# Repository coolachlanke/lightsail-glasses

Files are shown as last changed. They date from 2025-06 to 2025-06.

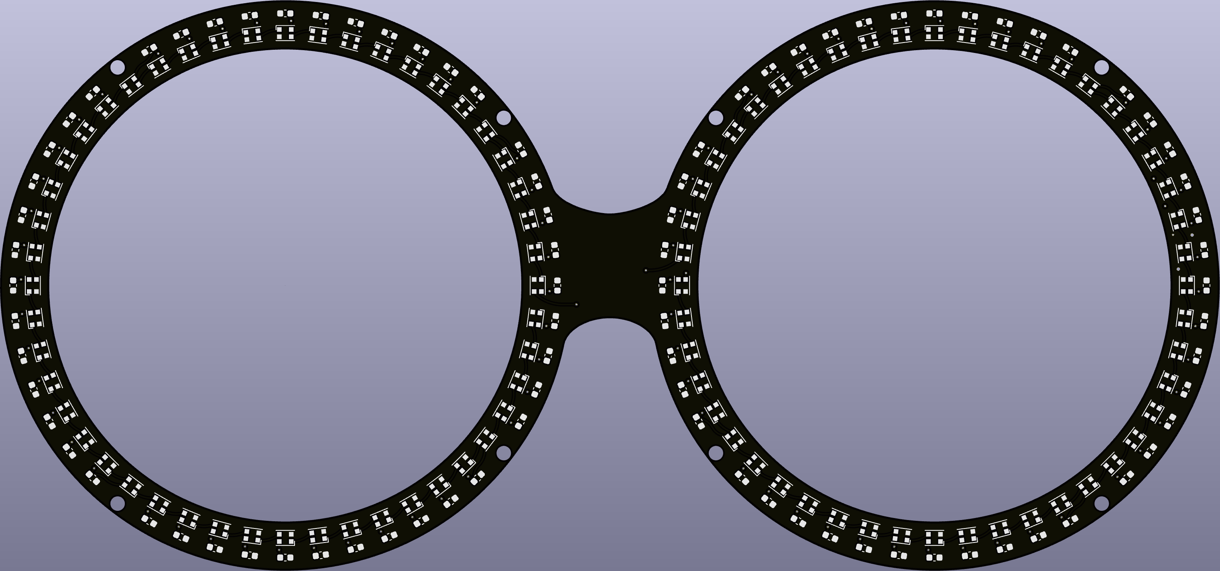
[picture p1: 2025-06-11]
Images/lsg_pcb_topsilk2.png

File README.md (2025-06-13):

# LightSail Glasses

**Colourful party glasses powered by WS2812B RGB LEDs, ESP32-C3, and WiFi.**  
Designed for festivals, raves, and fun.

---

## 🛠️ Tech Stack

- **Microcontroller:** ESP32-C3 (USB-C, WiFi)
- **PCBs:** Custom logic board and WS2812B carrier board developed with KiCAD 8
- **LEDs:** 2x WS2812B 48-pixel rings (96 total)
- **Power:** USB-C (5V) with onboard voltage regulation
- **Firmware:** Custom ESP32 firmware written in C++ in PlatformIO (Arduino framework)
- **App:** Custom ReactNative app for WiFi control
- **Animations:** Multiple visual modes, sinusoidal brightness effects, pulses, swirls, etc.

---

> Designed by Lachlan Cooke in late 2023.
> Check out [lachlancooke.com/projects](https://www.lachlancooke.com/projects) für mehr details.

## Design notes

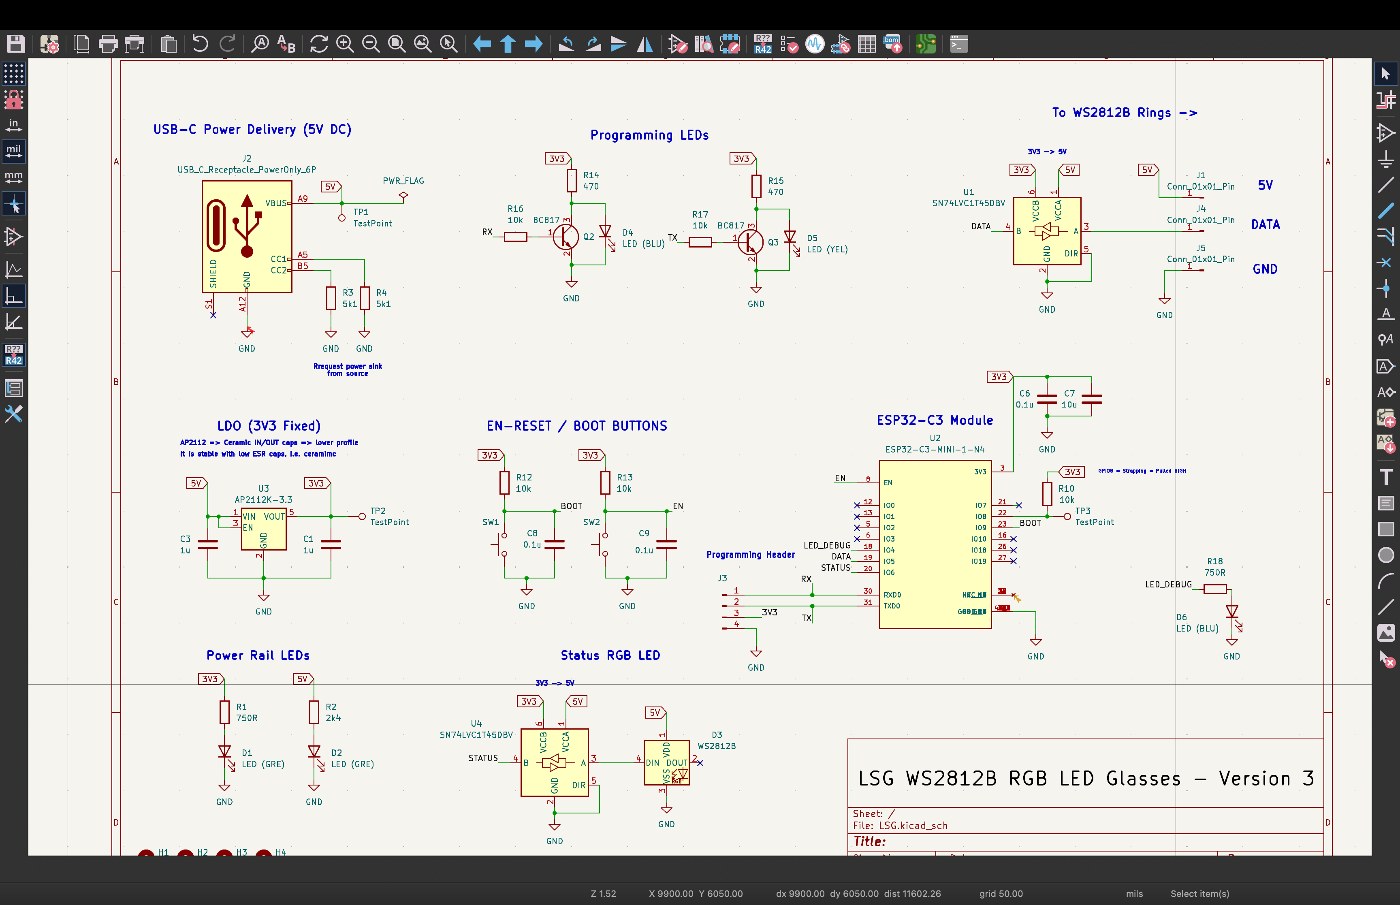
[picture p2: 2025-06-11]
Images/LSG_Logic_Schematic.png

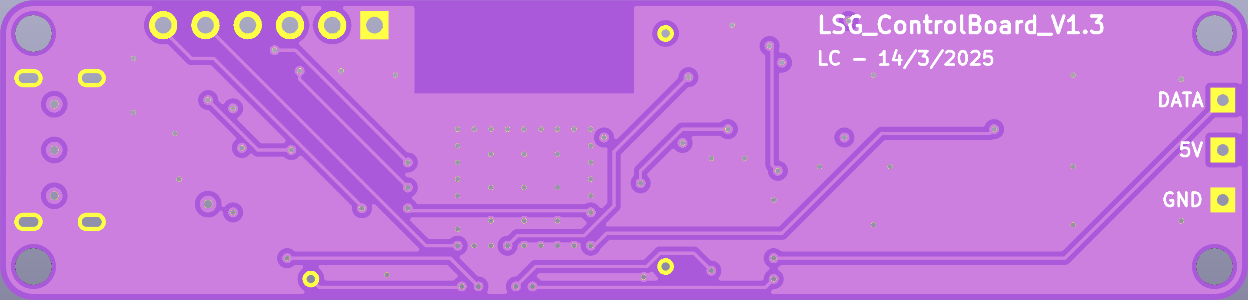
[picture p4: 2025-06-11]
Images/LSG_LogicPCB_V1.3_BottomSilk.png

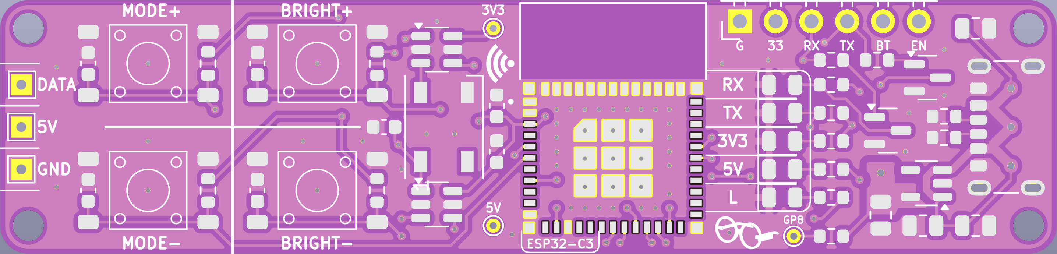
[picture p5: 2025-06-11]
Images/LSG_LogicPCB_V1.3_FrontSilk.png

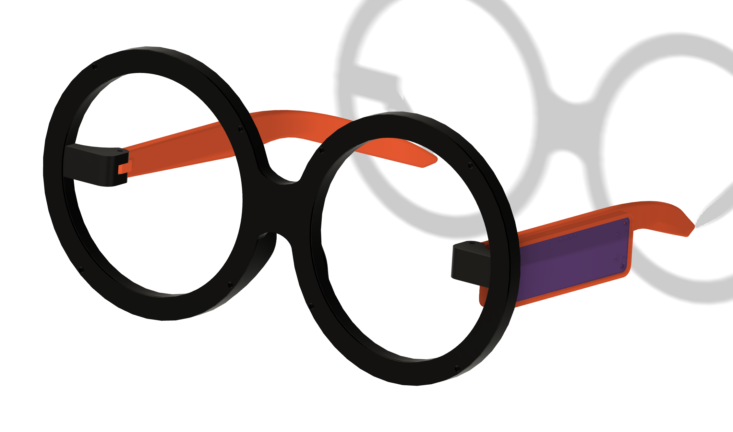
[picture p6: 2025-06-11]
Images/Glasses_Silk.png

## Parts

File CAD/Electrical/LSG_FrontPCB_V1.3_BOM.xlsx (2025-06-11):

Comment | Designator | Footprint | JLCPCB Part #
Cap 100nF 0603 | C1, C2, C3, C4, C5, C7, C8, C9, C10, C11, C12, C13, C14, C15, C16, C17, C19, C20, C21, C22, C23, C24, C25, C26, C27, C28, C29, C30, C31, C33, C34, C35, C36, C37, C38, C39, C40, C41, C42, C43, C45, C46, C47, C48, C49, C50, C51, C52, C53, C55, C56, C57, C58, C59, C60, C61, C62, C63, C64, C65, C67, C68, C69, C70, C71, C72, C73, C74, C75, C76, C77, C78, C79, C81, C82, C83, C84, C85, C86, C87, C88, C89, C90, C91, C93, C94, C95, C96 | Capacitor_SMD:C_0603_1608Metric | C1588
WS2812B 2020 | D1, D2, D3, D4, D5, D6, D7, D8, D9, D10, D11, D12, D13, D14, D15, D16, D17, D18, D19, D20, D21, D22, D23, D24, D25, D26, D27, D28, D29, D30, D31, D32, D33, D34, D35, D36, D37, D38, D39, D40, D41, D42, D43, D44, D45, D46, D47, D48, D49, D50, D51, D52, D53, D54, D55, D56, D57, D58, D59, D60, D61, D62, D63, D64, D65, D66, D67, D68, D69, D70, D71, D72, D73, D74, D75, D76, D77, D78, D79, D80, D81, D82, D83, D84, D85, D86, D87, D88, D89, D90, D91, D92, D93, D94, D95, D96 | LED_SMD:LED_WS2812B-2020_PLCC4_2.0x2.0mm | C965555

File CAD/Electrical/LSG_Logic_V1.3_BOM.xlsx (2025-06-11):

Comment | Designator | Footprint | JLCPCB Part #
1u 0805 | C1,C3 | Capacitor_SMD:C_0805_2012Metric | C28323
0.1u 0603 | C2,C4,C5,C6,C8,C10 | Capacitor_SMD:C_0603_1608Metric | C1588
10u 0603 | C7 | Capacitor_SMD:C_0603_1608Metric | C19702
10u 0805 | C11,C12 | Capacitor_SMD:C_0805_2012Metric | C15850
LED (GRE) 0805 | D1,D2 | Diode_SMD:D_0805_2012Metric | C965815
WS2812B | D3 | LED_SMD:LED_WS2812B_PLCC4_5.0x5.0mm_P3.2mm | C2843785
LED (BLU) 0805 | D4,D6 | Diode_SMD:D_0805_2012Metric | C965817
LED (YEL) 0805 | D5 | Diode_SMD:D_0805_2012Metric | C965814
USB_C_Receptacle_PowerOnly_6P | J2 | Connector_USB:USB_C_Receptacle_GCT_USB4125-xx-x-0190_6P_TopMnt_Horizontal | C456012
BC817 | Q2,Q3 | Package_TO_SOT_SMD:SOT-23 | C52801
750R 0603 | R1,R18 | Resistor_SMD:R_0603_1608Metric | C25257
2k4 0603 | R2 | Resistor_SMD:R_0603_1608Metric | C22940
5k1 0603 | R3,R4 | Resistor_SMD:R_0603_1608Metric | C105580
10k 0603 | R5,R6,R7,R8,R10,R16,R17 | Resistor_SMD:R_0603_1608Metric | C98220
470R 0603 | R14,R15 | Resistor_SMD:R_0603_1608Metric | C23179
SW_Push | SW3,SW4,SW5,SW7 | LC_CustomFootprint:SW_PUSH_6.0mm_SMT | C255812
SN74LVC1T45DBV | U1,U4 | Package_TO_SOT_SMD:SOT-23-6 | C7843
ESP32-C3-MINI-1-N4 | U2 | ESP32_C3_MINI_1_N4:XCVR_ESP32-C3-MINI-1-N4 | C2838502
AP2112K-3.3 | U3 | Package_TO_SOT_SMD:SOT-23-5 | C51118

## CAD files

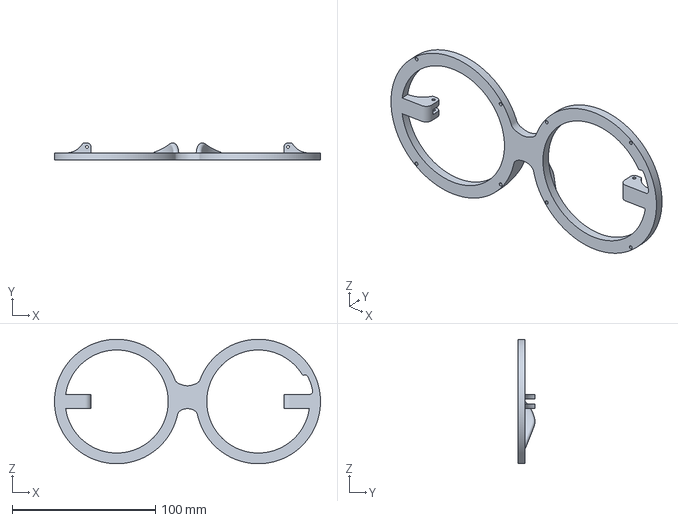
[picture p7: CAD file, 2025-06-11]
CAD/Mechanical/LSG_Mainframe_V1.3.3mf
186.0 x 12.0 x 87.0 mm

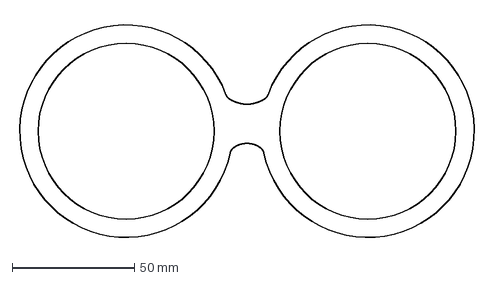
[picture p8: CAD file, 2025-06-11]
CAD/Mechanical/LSG_FrontPCB_EdgeCuts5.dxf
188.9 x 92.0 mm

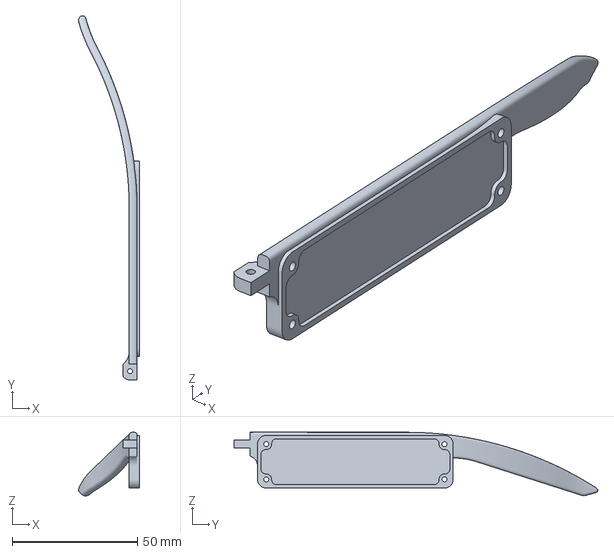
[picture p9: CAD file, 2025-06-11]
CAD/Mechanical/LSG_RightTemple_V1.3.3mf
24.4 x 145.0 x 25.3 mm

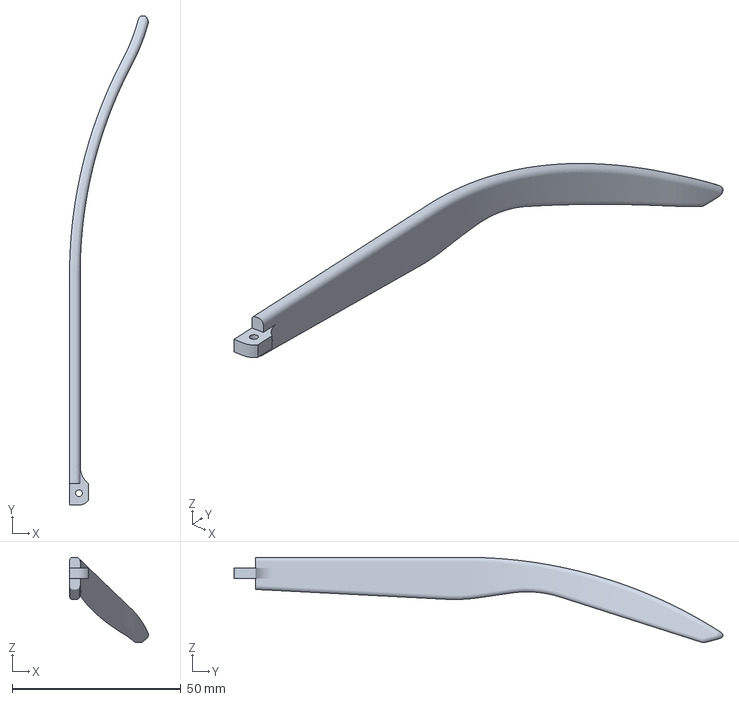
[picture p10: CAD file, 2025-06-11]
CAD/Mechanical/LSG_LeftTemple_V1.3.3mf
23.4 x 145.0 x 25.3 mm

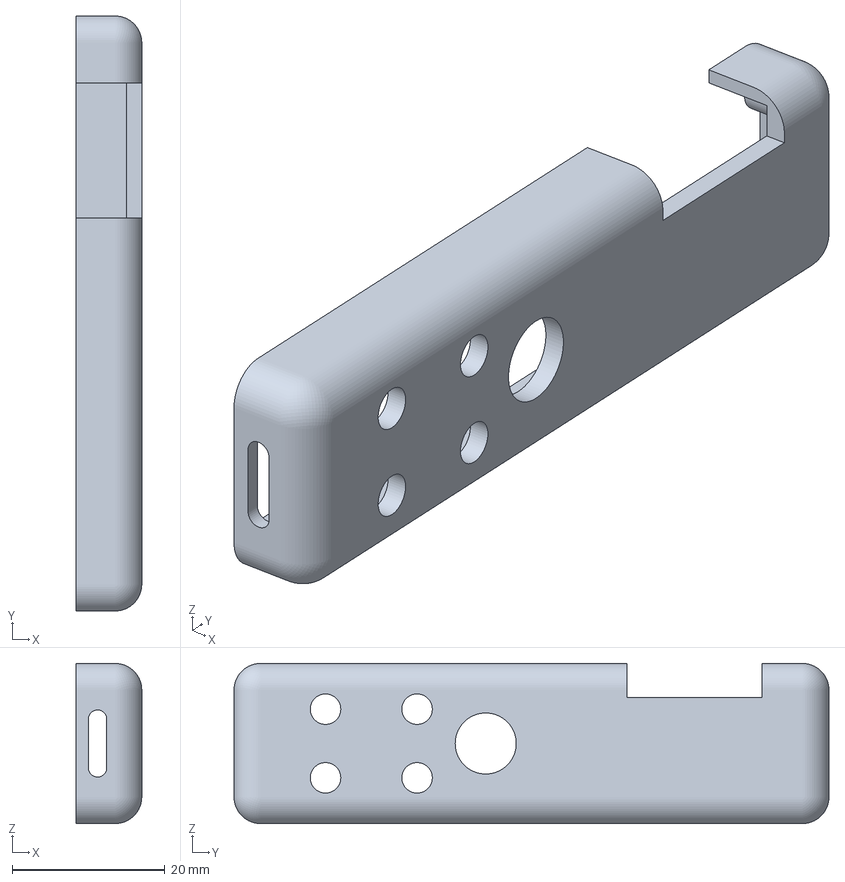
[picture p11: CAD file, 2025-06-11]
CAD/Mechanical/LSG_LogicPCB_Cover_DEBUG.3mf
8.60 x 78.0 x 21.0 mm

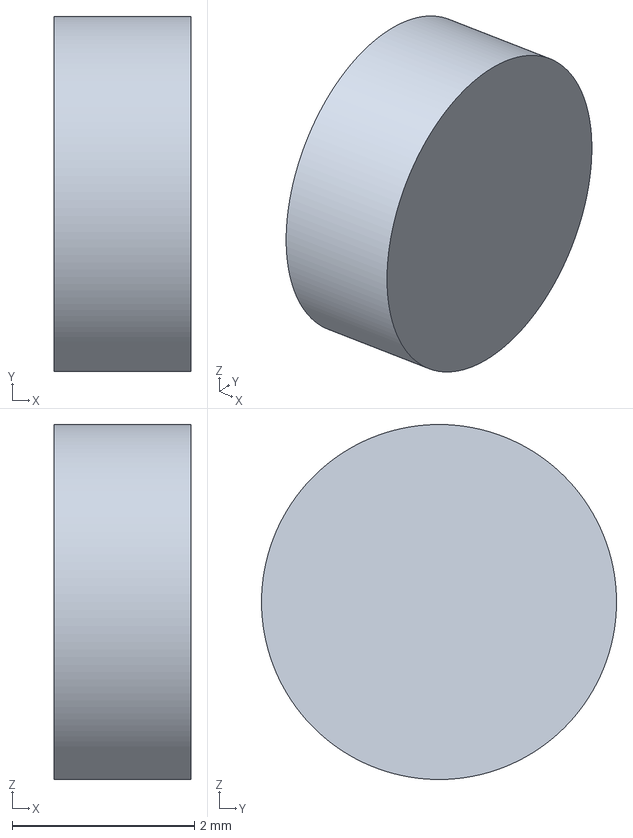
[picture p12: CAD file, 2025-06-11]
CAD/Mechanical/LSG_ButtonY_V1.3.3mf
1.50 x 3.90 x 3.90 mm

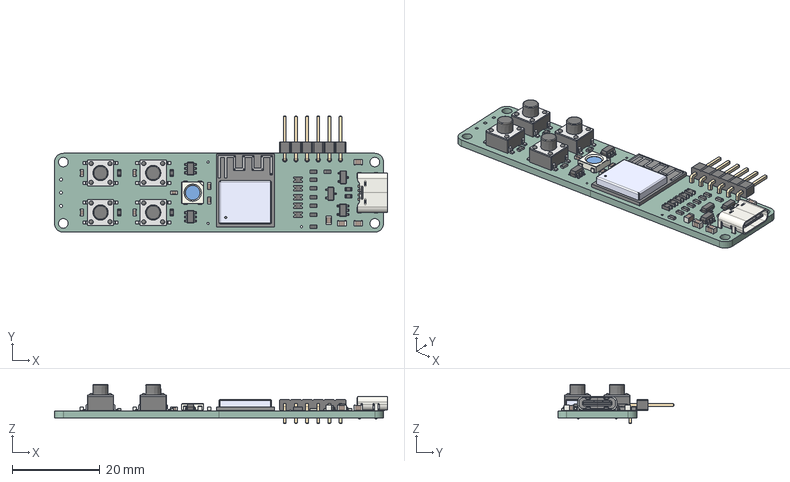
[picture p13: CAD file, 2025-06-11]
CAD/Mechanical/LSG_LogicPCB_V1.3_Model.step
75.9 x 26.5 x 9.00 mm
R_0603_1608Metric x 14
C_0603_1608Metric x 7
D_0805 x 5
Tactile Switch 6mm - SMT x 4
LED_WS2812B_PLCC4_50x50mm_P32mm
C_0805_2012Metric x 4
SOT_23_6 x 2
SOT_23 x 2
ESP32-C3-MINI-1-N4
USB_C_Receptacle_GCT_USB4125-xx-x_6P_TopMnt_Horizontal
SOT_23_5
PinHeader_1x06_P254mm_Horizontal
_autosave-LSG_PCB

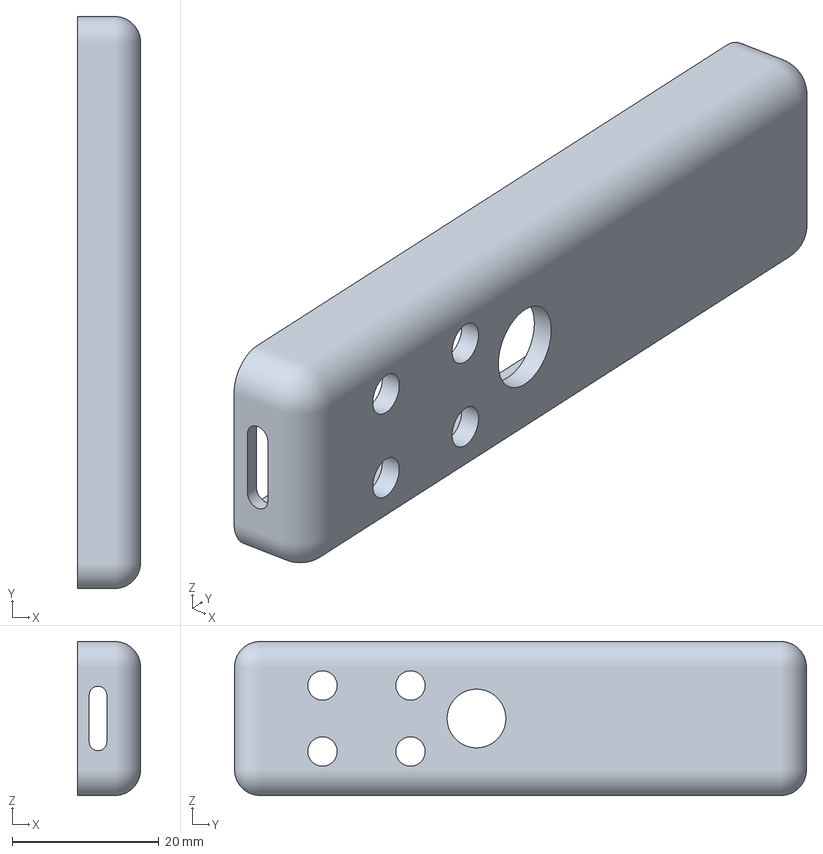
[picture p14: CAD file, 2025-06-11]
CAD/Mechanical/LSG_LogicPCBCover_V1.3.3mf
8.60 x 78.0 x 21.0 mm

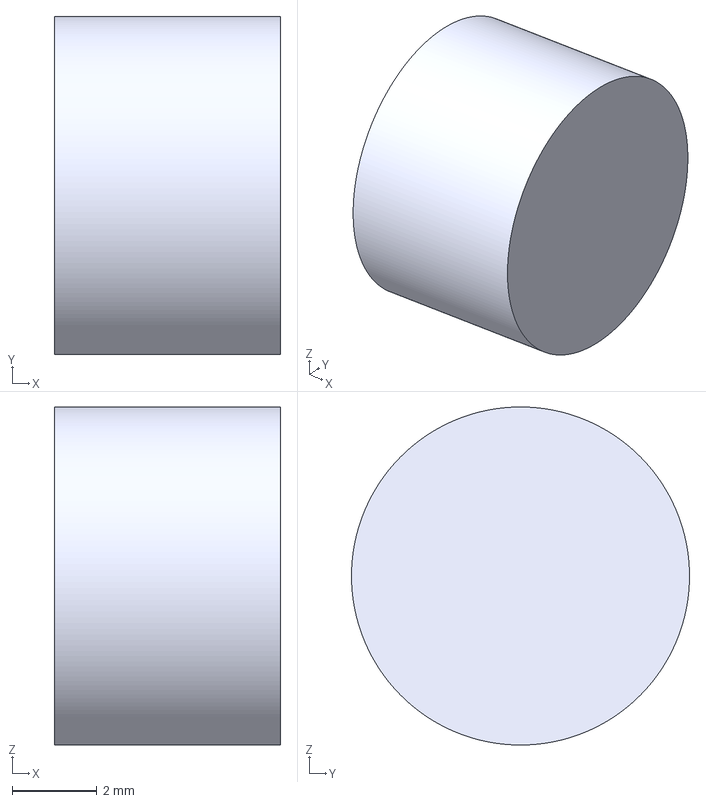
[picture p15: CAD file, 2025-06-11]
CAD/Mechanical/LSG_StatusLED_Diffuser.3mf
5.35 x 8.00 x 8.00 mm

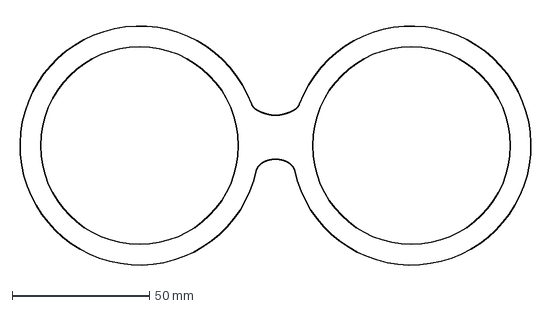
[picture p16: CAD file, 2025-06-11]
CAD/Mechanical/LSG_FrontPCB_EdgeCuts3.dxf
188.9 x 92.0 mm

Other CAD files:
CAD/Mechanical/LSG_LogicPCB_Cover_DEBUG2.3mf
CAD/Mechanical/LSG_StatusLEDDiffuser_V1.3.3mf

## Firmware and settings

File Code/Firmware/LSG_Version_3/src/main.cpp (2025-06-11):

#include <FastLED.h>
#include <Adafruit_NeoPixel.h>
#include <WiFi.h>
#include <WebServer.h>
#include <math.h>

// ------------------------------
// Hardware & Pin Definitions
// ------------------------------
#define NUM_LEDS         96      // Total LEDs for the two rings (48 per ring)
#define RING_LEDS        48      // LEDs per ring
#define RING_DATA_PIN    5       // Data pin for the rings (GPIO5)
#define STATUS_LED_PIN   6       // Data pin for the status LED (GPIO6)

// Button pins (active LOW with internal pull-ups)
#define BUTTON_MODE_INC   1      // GPIO1: Increment mode
#define BUTTON_MODE_DEC   3      // GPIO3: Decrement mode
#define BUTTON_BRIGHT_INC 2      // GPIO2: Increase brightness
#define BUTTON_BRIGHT_DEC 4      // GPIO4: Decrease brightness

// ------------------------------
// Global Variables
// ------------------------------
volatile int currentMode = 0;        // Current mode (0 to numModes-1)
const int numModes = 27;              // Total modes: 0..26
volatile int ringBrightness = 50;     // LED ring brightness (0-255)

CRGB leds[NUM_LEDS];                 // FastLED array for the rings
Adafruit_NeoPixel statusLED(1, STATUS_LED_PIN, NEO_GRB + NEO_KHZ800); // Single status LED

// ------------------------------
// WiFi & Web Server Setup in AP Mode
// ------------------------------

// New WiFi credentials for AP mode
const char* apSSID = "SmartGlassesP3";
const char* apPassword = "glasses2025";  // Choose a secure password

// Set up the WebServer on port 80
WebServer server(80);

// ------------------------------
// Forward Declarations of Tasks
// ------------------------------
void setupWiFi(void * parameter);
void webServerTask(void * parameter);
void ledRingTask(void * parameter);
void statusLEDTask(void * parameter);
void buttonTask(void * parameter);

// ------------------------------
// Utility Functions
// ------------------------------

// Gamma correction for perceptually linear brightness.
uint8_t gammaCorrect(uint8_t value) {
  float normalized = value / 255.0;
  normalized = pow(normalized, 2.2);
  return (uint8_t)(normalized * 255.0);
}

// Evenly distribute the 256 hue values over 'ringSize' LEDs using error accumulation.
void fill_ring_with_exact_rainbow(CRGB *ring, uint8_t ringSize, uint8_t startHue) {
  const float baseIncrement = 5.0;                   // floor(256/48) = 5
  const float exactStep = 256.0 / ringSize;            // ~5.33333
  const float fractional = exactStep - baseIncrement;  // ~0.33333
  
  float hue = startHue;
  float error = 0.0;
  for (uint8_t i = 0; i < ringSize; i++) {
    ring[i] = CHSV((uint8_t)hue, 255, 255);
    hue += baseIncrement;
    error += fractional;
    if (error >= 1.0) {
      hue += 1;
      error -= 1.0;
    }
  }
}

// ------------------------------
// FreeRTOS Task: WiFi Setup in AP Mode
// ------------------------------
void setupWiFi(void * parameter) {
  // Set the ESP32 to AP mode.
  WiFi.mode(WIFI_AP);
  // Start the soft AP with the given SSID and password.
  WiFi.softAP(apSSID, apPassword);
  Serial.println("ESP32 running in AP mode");
  Serial.print("AP IP address: ");
  Serial.println(WiFi.softAPIP());
  // In AP mode, we don't wait for a connection.
  vTaskDelete(NULL); // End task once AP is set up.
}

// ------------------------------
// FreeRTOS Task: Web Server
// ------------------------------
void handleRoot() {
  server.send(200, "text/plain", "SmartGlasses ESP32");
}

void handleSet() {
  if (server.hasArg("mode")) {
    int modeVal = server.arg("mode").toInt();
    if (modeVal >= 0 && modeVal < numModes) {
      currentMode = modeVal;
    }
  }
  if (server.hasArg("brightness")) {
    int brightVal = server.arg("brightness").toInt();
    if (brightVal >= 0 && brightVal <= 255) {
      ringBrightness = brightVal;
      FastLED.setBrightness(ringBrightness);
    }
  }
  server.sendHeader("Location", "/", true);
  server.send(302, "text/plain", "");
}

void webServerTask(void * parameter) {
  server.on("/", handleRoot);
  server.on("/set", handleSet);
  server.begin();
  Serial.println("Web server started in AP mode");
  while (1) {
    server.handleClient();
    vTaskDelay(10 / portTICK_PERIOD_MS);
  }
}

// ------------------------------
// FreeRTOS Task: LED Ring Updates
// ------------------------------
void ledRingTask(void * parameter) {
  // Variables for modes that need persistent state.
  static uint8_t startHueRing1 = 0;
  static uint8_t startHueRing2 = 0;
  
  // For Theatre Chase (mode 3)
  static uint8_t theatreOffset = 0;
  
  // For Side Wipe (mode 4)
  static int wipeExp = 0;                // Expansion counter for the wipe effect
  static CRGB wipeColor = CRGB::Blue;    // Starting wipe color
  static bool sideWipeInitialized = false; // Flag to clear the ring when mode is first entered
  if (currentMode != 4) {
    sideWipeInitialized = false;
  }

  // Global hue for the new modes:
  static uint8_t gHue = 0;  


  while (1) {
    switch(currentMode) {
      case 0: // Rainbow cycle
        fill_ring_with_exact_rainbow(leds, RING_LEDS, startHueRing1);
        fill_ring_with_exact_rainbow(leds + RING_LEDS, RING_LEDS, startHueRing2);
        startHueRing1++;
        startHueRing2++;
        FastLED.show();
        vTaskDelay(10 / portTICK_PERIOD_MS);
        break;
        
      case 1: // Solid blue
        fill_solid(leds, NUM_LEDS, CRGB::Blue);
        FastLED.show();
        vTaskDelay(50 / portTICK_PERIOD_MS);
        break;
        
      case 2: // Flash white
        {
          static bool toggle = false;
          fill_solid(leds, NUM_LEDS, toggle ? CRGB::White : CRGB::Black);
          toggle = !toggle;
        }
        FastLED.show();
        vTaskDelay(100 / portTICK_PERIOD_MS);
        break;
        
      case 3: // Theatre chase
        {
          fill_solid(leds, NUM_LEDS, CRGB::Black);
          for (int i = 0; i < NUM_LEDS; ++i) {
            if ((i + theatreOffset) % 3 == 0) {
              leds[i] = CRGB::White;
            }
          }
          theatreOffset++;
          FastLED.show();
          vTaskDelay(50 / portTICK_PERIOD_MS);
        }
        break;
        
      case 4: // Side wipe
        {
          // On first entry to Mode 4, clear the ring.
          if (!sideWipeInitialized) {
            fill_solid(leds, NUM_LEDS, CRGB::Black);
            FastLED.show();
            wipeExp = 0;
            sideWipeInitialized = true;
            vTaskDelay(50 / portTICK_PERIOD_MS);
          }
          
          // For Ring 1 (LEDs 0..47): 
          // The wipe starts at the center (LED 0) and moves outward.
          // We assume the ring is arranged such that index 0 is the center,
          // and the numbers increase clockwise until 47 brings you back to the center.
          int idx1 = wipeExp;          // Moving from center outwards.
          int idx2 = 47 - wipeExp;       // The opposite side.
          if (idx1 <= idx2) {            // Ensure we don't overlap.
            leds[idx1] = wipeColor;
            leds[idx2] = wipeColor;
          }
          
          // For Ring 2 (LEDs 48..95): 
          // It starts at LED 48 (center) and moves outward; 95 is the other center.
          int idx3 = 48 + wipeExp;
          int idx4 = 95 - wipeExp;
          if (idx3 <= idx4) {
            leds[idx3] = wipeColor;
            leds[idx4] = wipeColor;
          }
          
          FastLED.show();
          vTaskDelay(15 / portTICK_PERIOD_MS); // Faster update
          
          wipeExp++;
          if (wipeExp > 24) {  // When the wipe covers half the ring.
            wipeExp = 0;
            // Toggle the wipe color so the new color overlays the old.
            wipeColor = (wipeColor == CRGB::Blue) ? CRGB::Red : CRGB::Blue;
          }
        }
        break;

      case 5: // Sparkle mode
        {
          fadeToBlackBy(leds, NUM_LEDS, 10);
          int pos = random(NUM_LEDS);
          leds[pos] = CHSV(random(256), 200, 255);
          FastLED.show();
          vTaskDelay(30 / portTICK_PERIOD_MS);
        }
        break;

      case 6: { // Mode 6: Sinelon – moving colored dot with trailing fade on each ring.
        // Fade out the background slightly.
        fadeToBlackBy(leds, NUM_LEDS, 20);
        
        // For Ring 1 (indices 0 to RING_LEDS-1), moving dot using beatsin8.
        uint8_t pos1 = beatsin8(10, 0, RING_LEDS - 1);
        leds[pos1] += CHSV(gHue, 200, 255);
        
        // For Ring 2 (indices RING_LEDS to NUM_LEDS-1), reverse the mapping so it moves counterclockwise.
        uint8_t pos2 = beatsin8(10, 0, RING_LEDS - 1);
        uint8_t pos2Mapped = (RING_LEDS - 1) - pos2;
        leds[RING_LEDS + pos2Mapped] += CHSV(gHue + 64, 200, 255);
        
        FastLED.show();
        vTaskDelay(20 / portTICK_PERIOD_MS);
        gHue++; // Advance global hue.
      }
        break;
      
      case 7: { // Mode 7: Juggle – multiple colored dots moving on each ring.
        fadeToBlackBy(leds, NUM_LEDS, 20);
        // For Ring 1, draw 4 moving dots.
        for (uint8_t i = 0; i < 4; i++) {
            int pos = beatsin16(7 + i, 0, RING_LEDS - 1, 0, i * 1000);
            leds[pos] += CHSV(gHue + i * 32, 200, 255);
        }
        // For Ring 2, do the same but reverse the index mapping.
        for (uint8_t i = 0; i < 4; i++) {
            int pos = beatsin16(7 + i, 0, RING_LEDS - 1, 0, i * 1000);
            uint8_t posMapped = (RING_LEDS - 1) - pos;
            leds[RING_LEDS + posMapped] += CHSV(gHue + 128 + i * 32, 200, 255);
        }
        FastLED.show();
        vTaskDelay(20 / portTICK_PERIOD_MS);
        gHue++;
      }
        break;
        
      case 8: // Running Lights – a moving bright dot on each ring with a fading trail.
        {
          // Static indices for the running dot in each ring.
          static int runIndex1 = 0;
          static int runIndex2 = 0;
          // Fade the entire strip slightly to create a trailing effect.
          fadeToBlackBy(leds, NUM_LEDS, 50);
          // For Ring 1 (indices 0 to RING_LEDS-1), light up the current dot.
          leds[runIndex1] = CRGB::White;
          // For Ring 2 (indices RING_LEDS to NUM_LEDS-1), light up the current dot.
          leds[runIndex2 + RING_LEDS] = CRGB::White;
          FastLED.show();
          vTaskDelay(30 / portTICK_PERIOD_MS);
          runIndex1 = (runIndex1 + 1) % RING_LEDS;
          runIndex2 = (runIndex2 + 1) % RING_LEDS;
        }
        break;

      case 9: { // Laser Sweep effect – a narrow, bright band that moves along each ring
          const int bandWidth = 3; // Width of the laser band
          // Use static variables for head position on each ring.
          static int laserPos1 = 0;
          static int laserPos2 = 0;
          // Fade the rings slightly to produce a trailing effect.
          fadeToBlackBy(leds, NUM_LEDS, 40);
          // For Ring 1 (indices 0 to RING_LEDS-1), move clockwise.
          for (int i = 0; i < bandWidth; i++) {
              int pos = (laserPos1 + i) % RING_LEDS;
              leds[pos] = CHSV(gHue, 255, 255);
          }
          // For Ring 2 (indices RING_LEDS to NUM_LEDS-1), reverse the index for a counterclockwise sweep.
          for (int i = 0; i < bandWidth; i++) {
              int pos = (laserPos2 + i) % RING_LEDS;
              int mappedPos = (RING_LEDS - 1) - pos;
              leds[RING_LEDS + mappedPos] = CHSV(gHue + 64, 255, 255);
          }
          FastLED.show();
          vTaskDelay(20 / portTICK_PERIOD_MS);
          laserPos1 = (laserPos1 + 1) % RING_LEDS;
          laserPos2 = (laserPos2 + 1) % RING_LEDS;
          gHue++;
      }
        break;
      
      case 10: { // Strobe Fade effect – a rapid strobe flash that then fades out
          static bool strobeOn = false;
          static int strobeCount = 0;
          if (strobeOn) {
              // Flash the entire rings with a bright color.
              fill_solid(leds, NUM_LEDS, CHSV(gHue, 255, ringBrightness));
              FastLED.show();
              vTaskDelay(30 / portTICK_PERIOD_MS);
              strobeCount++;
              if (strobeCount > 2) { // after a few flashes, turn off strobe
                  strobeOn = false;
                  strobeCount = 0;
              }
          } else {
              // Fade the rings to black.
              fadeToBlackBy(leds, NUM_LEDS, 80);
              FastLED.show();
              vTaskDelay(30 / portTICK_PERIOD_MS);
              // Random chance to restart strobe.
              if (random8() < 50) {
                  strobeOn = true;
              }
          }
          gHue++;
      }
        break;
      
      case 11: { // Orbiting Comets effect – two bright comets per ring orbit with trailing fades
          static int cometPos1 = 0;
          static int cometPos2 = 0;
          // Create fading trails.
          fadeToBlackBy(leds, NUM_LEDS, 40);
          // For Ring 1, plot two comets.
          leds[cometPos1] = CHSV(gHue, 255, 255);
          leds[cometPos2] = CHSV(gHue + 32, 255, 255);
          // For Ring 2, reverse mapping so motion appears counterclockwise.
          int mapped1 = (RING_LEDS - 1) - cometPos1;
          int mapped2 = (RING_LEDS - 1) - cometPos2;
          leds[RING_LEDS + mapped1] = CHSV(gHue + 64, 255, 255);
          leds[RING_LEDS + mapped2] = CHSV(gHue + 96, 255, 255);
          FastLED.show();
          vTaskDelay(30 / portTICK_PERIOD_MS);
          cometPos1 = (cometPos1 + 1) % RING_LEDS;
          cometPos2 = (cometPos2 + 2) % RING_LEDS; // different speed for variety
          gHue++;
      }
        break;
      
      case 12: { // Color Bounce effect – a bouncing ball of color on each ring with trailing fade
          static int bouncePos1 = 0;
          static int bounceDir1 = 1;  // 1: forward, -1: backward
          static int bouncePos2 = 0;
          static int bounceDir2 = 1;
          // Fade the rings to create a trailing effect.
          fadeToBlackBy(leds, NUM_LEDS, 50);
          // For Ring 1, light the bouncing dot.
          leds[bouncePos1] = CHSV(gHue, 255, 255);
          // For Ring 2, reverse mapping for the bouncing dot.
          int mappedBounce = (RING_LEDS - 1) - bouncePos2;
          leds[RING_LEDS + mappedBounce] = CHSV(gHue + 64, 255, 255);
          FastLED.show();
          vTaskDelay(40 / portTICK_PERIOD_MS);
          bouncePos1 += bounceDir1;
          if (bouncePos1 >= RING_LEDS - 1 || bouncePos1 <= 0) {
              bounceDir1 = -bounceDir1;
          }
          bouncePos2 += bounceDir2;
          if (bouncePos2 >= RING_LEDS - 1 || bouncePos2 <= 0) {
              bounceDir2 = -bounceDir2;
          }
          gHue++;
      }
        break;
      
      case 13: { // Psychedelic Swirl effect – an organic noise-based pattern that evolves over time
          static uint16_t swirlX = 0;
          // For Ring 1:
          for (int i = 0; i < RING_LEDS; i++) {
              uint8_t noise = inoise8(i * 40 + swirlX);
              leds[i] = CHSV(noise, 255, ringBrightness);
          }
          // For Ring 2, reverse the index order.
          for (int i = 0; i < RING_LEDS; i++) {
              uint8_t noise = inoise8(i * 40 + swirlX);
              int mapped = (RING_LEDS - 1) - i;
              leds[RING_LEDS + mapped] = CHSV(noise + 64, 255, ringBrightness);
          }
          FastLED.show();
          vTaskDelay(20 / portTICK_PERIOD_MS);
          swirlX += 30;
      }
        break;

      case 14: { // Neon Grid effect – alternating moving stripes on each ring
          const int stripeWidth = 4; // number of LEDs per stripe
          int offset = gHue % (stripeWidth * 2); // dynamic offset based on global hue
          // For Ring 1:
          for (int i = 0; i < RING_LEDS; i++) {
              if (((i + offset) % (stripeWidth * 2)) < stripeWidth) {
                  leds[i] = CHSV(gHue, 255, ringBrightness);
              } else {
                  leds[i] = CRGB::Black;
              }
          }
          // For Ring 2 (reverse-mapped):
          for (int i = 0; i < RING_LEDS; i++) {
              int mapped = (RING_LEDS - 1) - i;
              if (((i + offset) % (stripeWidth * 2)) < stripeWidth) {
                  leds[RING_LEDS + mapped] = CHSV(gHue + 64, 255, ringBrightness);
              } else {
                  leds[RING_LEDS + mapped] = CRGB::Black;
              }
          }
          FastLED.show();
          vTaskDelay(30 / portTICK_PERIOD_MS);
          gHue++; 
      }
      break;
      
      case 15: { // Echo Waves – a sine-wave brightness pattern traveling around each ring
          // For Ring 1:
          for (int i = 0; i < RING_LEDS; i++) {
              uint8_t bri = sin8(i * 10 + gHue);
              leds[i] = CHSV(gHue, 255, bri);
          }
          // For Ring 2 (reverse order):
          for (int i = 0; i < RING_LEDS; i++) {
              uint8_t bri = sin8(i * 10 + gHue);
              int mapped = (RING_LEDS - 1) - i;
              leds[RING_LEDS + mapped] = CHSV(gHue + 96, 255, bri);
          }
          FastLED.show();
          vTaskDelay(20 / portTICK_PERIOD_MS);
          gHue++;
      }
        break;
      
      case 16: { // Firefly Dance – random firefly-like dots appear and fade on each ring
          // Fade the entire array slightly to create trails.
          fadeToBlackBy(leds, NUM_LEDS, 30);
          // Randomly light up a dot on Ring 1.
          if (random8() < 80) {
              int pos = random(RING_LEDS);
              leds[pos] = CHSV(gHue, 200, 255);
          }
          // And on Ring 2 (with reverse mapping).
          if (random8() < 80) {
              int pos = random(RING_LEDS);
              int mapped = (RING_LEDS - 1) - pos;
              leds[RING_LEDS + mapped] = CHSV(gHue + 64, 200, 255);
          }
          FastLED.show();
          vTaskDelay(30 / portTICK_PERIOD_MS);
          gHue++;
      }
        break;
      
      case 17: { // Spinning Bar – a wide colored bar rotates around each ring
          const int barWidth = 6; // width of the bar
          // For Ring 1:
          static int barPos1 = 0;
          fill_solid(leds, RING_LEDS, CRGB::Black);
          for (int i = 0; i < barWidth; i++) {
              int pos = (barPos1 + i) % RING_LEDS;
              leds[pos] = CHSV(gHue, 255, ringBrightness);
          }
          // For Ring 2 (reverse-mapped):
          static int barPos2 = 0;
          fill_solid(leds + RING_LEDS, RING_LEDS, CRGB::Black);
          for (int i = 0; i < barWidth; i++) {
              int pos = (barPos2 + i) % RING_LEDS;
              int mapped = (RING_LEDS - 1) - pos;
              leds[RING_LEDS + mapped] = CHSV(gHue + 64, 255, ringBrightness);
          }
          FastLED.show();
          vTaskDelay(30 / portTICK_PERIOD_MS);
          barPos1 = (barPos1 + 1) % RING_LEDS;
          barPos2 = (barPos2 + 1) % RING_LEDS;
          gHue++;
      }
        break;
      
      case 18: { // Liquid Ripple – a ripple emanates from a moving center on each ring
          // For Ring 1:
          static int rippleCenter1 = 0;
          for (int i = 0; i < RING_LEDS; i++) {
              int d = abs(i - rippleCenter1);
              // Since the ring is circular, take the shorter distance.
              d = min(d, RING_LEDS - d);
              uint8_t bri = 255 - d * (255 / (RING_LEDS / 2));
              bri = constrain(bri, 0, 255);
              leds[i] = CHSV(gHue, 255, bri);
          }
          // For Ring 2 (reverse-mapped):
          static int rippleCenter2 = 0;
          for (int i = 0; i < RING_LEDS; i++) {
              int d = abs(i - rippleCenter2);
              d = min(d, RING_LEDS - d);
              uint8_t bri = 255 - d * (255 / (RING_LEDS / 2));
              bri = constrain(bri, 0, 255);
              int mapped = (RING_LEDS - 1) - i;
              leds[RING_LEDS + mapped] = CHSV(gHue + 128, 255, bri);
          }
          FastLED.show();
          vTaskDelay(40 / portTICK_PERIOD_MS);
          rippleCenter1 = (rippleCenter1 + 1) % RING_LEDS;
          rippleCenter2 = (rippleCenter2 + 1) % RING_LEDS;
          gHue++;
      }
        break;

      case 19: { // Full Throttle Pulse effect: full-ring pulsing at high brightness
          // beatsin8 produces a sine wave oscillating between 220 and 255 at 30 BPM.
          uint8_t pulseVal = beatsin8(30, 220, 255);
          // Fill both rings uniformly.
          fill_solid(leds, NUM_LEDS, CHSV(gHue, 255, pulseVal));
          FastLED.show();
          vTaskDelay(20 / portTICK_PERIOD_MS);
          gHue++;  // Advance the hue for color variation.
      }
        break;

      case 20: { // Rave Strobe effect: rapid, full-bright color flashes
          // Fill Ring 1 with a bright color.
          fill_solid(leds, RING_LEDS, CHSV(gHue, 255, 255));
          // Fill Ring 2 similarly (using same color offset, since full fill means no mapping issues).
          fill_solid(leds + RING_LEDS, RING_LEDS, CHSV(gHue + 64, 255, 255));
          FastLED.show();
          vTaskDelay(20 / portTICK_PERIOD_MS);
          // Increase hue more rapidly for a very dynamic color cycle.
          gHue += 5;
      }
        break;

      case 21: { // Thunder Pulse effect: intermittent full-bright flashes with a strong pulse
          static int pulseCounter = 0;
          // Define base brightness and flash brightness.
          const uint8_t baseBri = 220;
          const uint8_t flashBri = 255;
          // For a 60-frame cycle, if the counter is less than 5, output a full flash.
          uint8_t bri = (pulseCounter % 60 < 5) ? flashBri : baseBri;
          // Fill both rings with the chosen brightness.
          fill_solid(leds, NUM_LEDS, CHSV(gHue, 255, bri));
          FastLED.show();
          vTaskDelay(30 / portTICK_PERIOD_MS);
          pulseCounter = (pulseCounter + 1) % 60;
          gHue++;
      }
        break;
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
void loop() {
  // Empty – all work is done in FreeRTOS tasks.
}
